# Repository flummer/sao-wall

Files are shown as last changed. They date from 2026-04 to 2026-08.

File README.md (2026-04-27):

# SAO Wall

This is a design for a large PCB (300x400mm) with 16 SAO connectors to work either as a standalone display (fits in an IKEA RÖDALM picture frame) or be monted along with other panels to form a larger wall for displaying many SAOs.

This is heavily inspired by [Brian Benchoffs SAO Wall](https://bbenchoff.github.io/pages/ShittyWall.html), that has been used at several Supercon events, but this design does a few things slightly different, not least the power setup.

## Main concept and idea

The design is separated into two parts:

- SAO Connector board, which is the large PCB, that has all the connectors, polyfuses for each output and then a set of connectors for hooking up to the 4 power rails, the 2 I2C busses and all the GPIO pins for all SAOs
- USB-C PD and Pico controll board is the smaller board that has the voltage regulators (4x AP63203WU-7 buck converters), USB-C PD controller (STUSB4531) and a footprint for a Raspberry Pi Pico (1 or 2).

The setup with two boards is done so that the more generic part (the connector PCB) that is also a bit on the expensive side can be ordered once and maybe a combined order for multiple people, and then the more opinionated element with the powering circuit and maybe a micro controller can be easier made in low volume (most simple is a piece of proto board and a simple 3.3v poser supply).

The USB-C PD power setup that is included here is meant to work nicely with most USB-C power supplies and at the same time be able to power all 16 SAOs to the full specification of the SAO standard (250mA @ 3.3V for each SAO).

The Raspberry Pi Pico is connected very similar to hos the [Hackaday SAO Badge](https://github.com/Hack-a-Day/2024-Supercon-8-Add-On-Badge) was made, with 2 I2C busses (using the same pins) and hooked up to GPIO pins of most of the SAOs (10 out of the 16) as there is a limited number of available connections on the Pico. It's not 100% pin compatible with the Hackaday SAO Badge, but it should be an easy tweak if you would like to run the same firmware.

## Designed in KiCad v10

To open the project, you will need to install the most recent release (v10), KiCad v9 or earlier won't open this design directly.

[Electronics schematics for the connector board as a PDF file](https://github.com/flummer/sao-wall/blob/main/sao-connector-board-schematics.pdf) and [Electronics schematics for the USB-C PD and Pico control board as a PDF file](https://github.com/flummer/sao-wall/blob/main/usb-pd-pico-controller-schematics.pdf) are included for reference.

## License

The hardware design of the `main` branch of this repository is released under the following license:

* the "Creative Commons Attribution-ShareAlike 4.0 International License"
  (CC BY-SA 4.0) full text of this license is included in the LICENSE file
  and a copy can also be found at
  [http://creativecommons.org/licenses/by-sa/4.0/](http://creativecommons.org/licenses/by-sa/4.0/)

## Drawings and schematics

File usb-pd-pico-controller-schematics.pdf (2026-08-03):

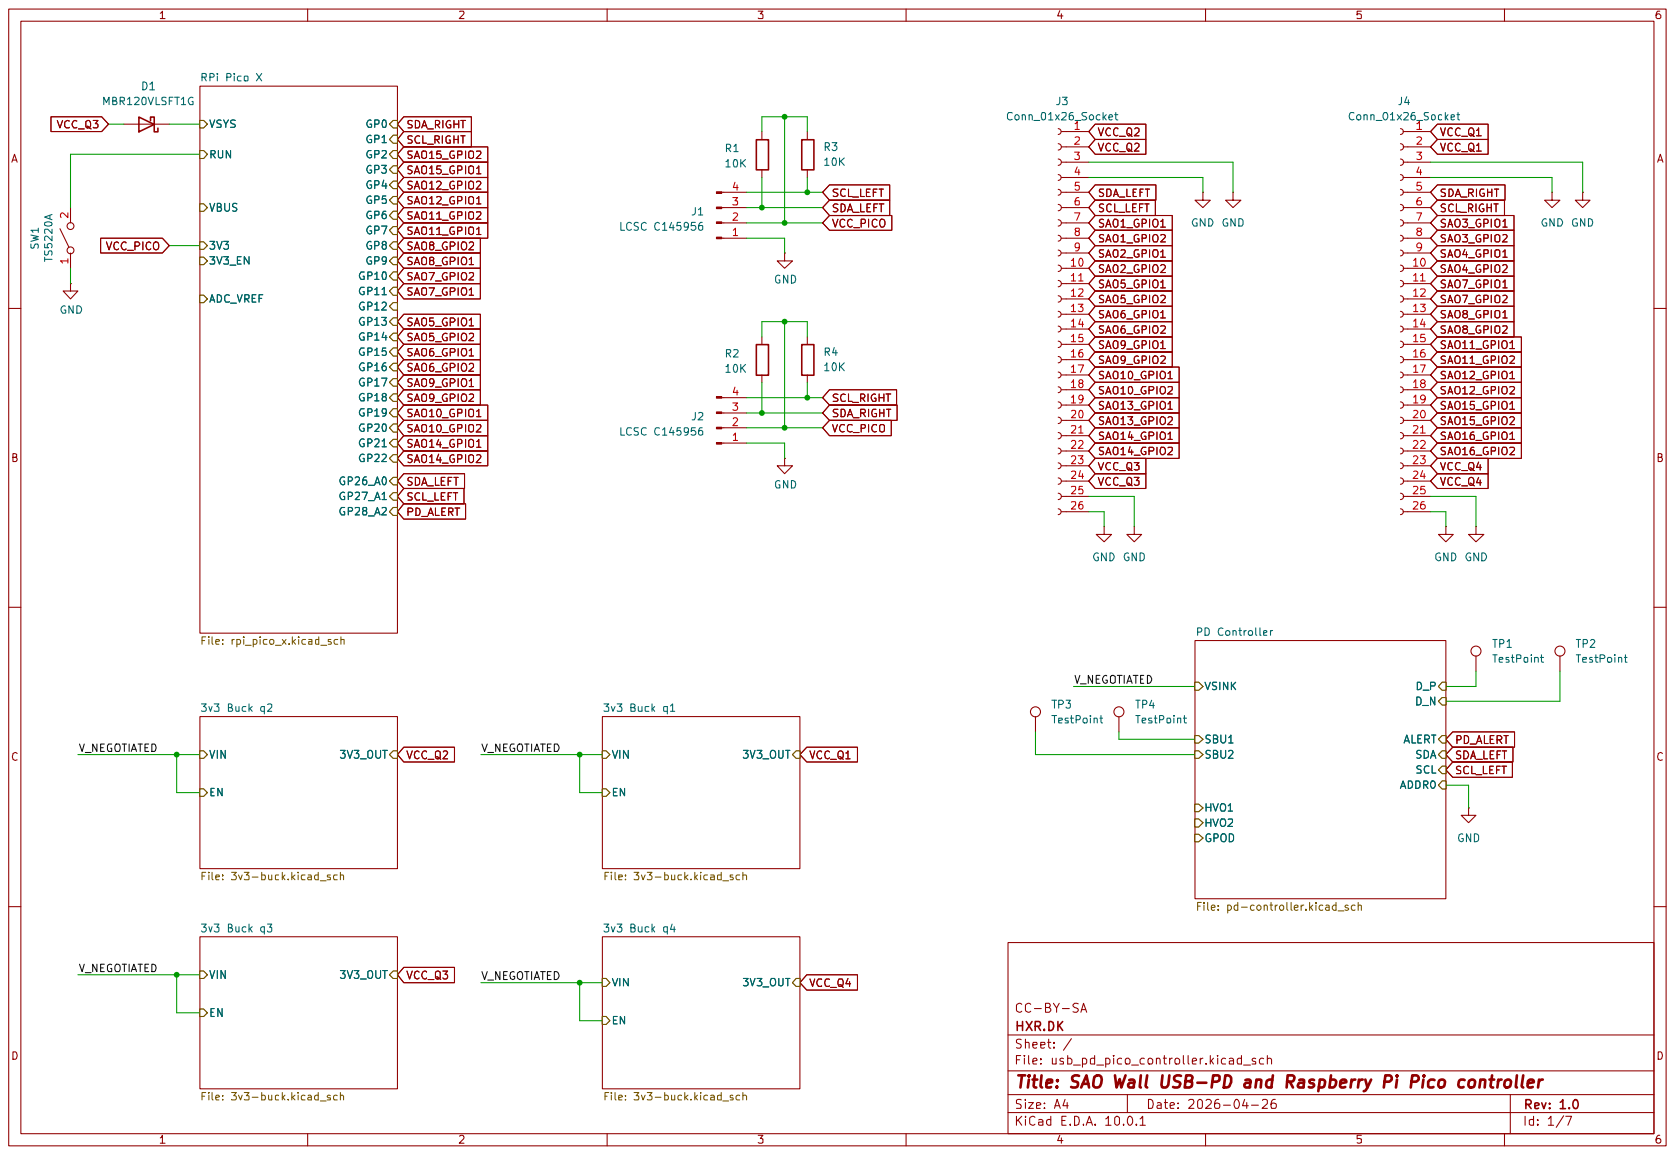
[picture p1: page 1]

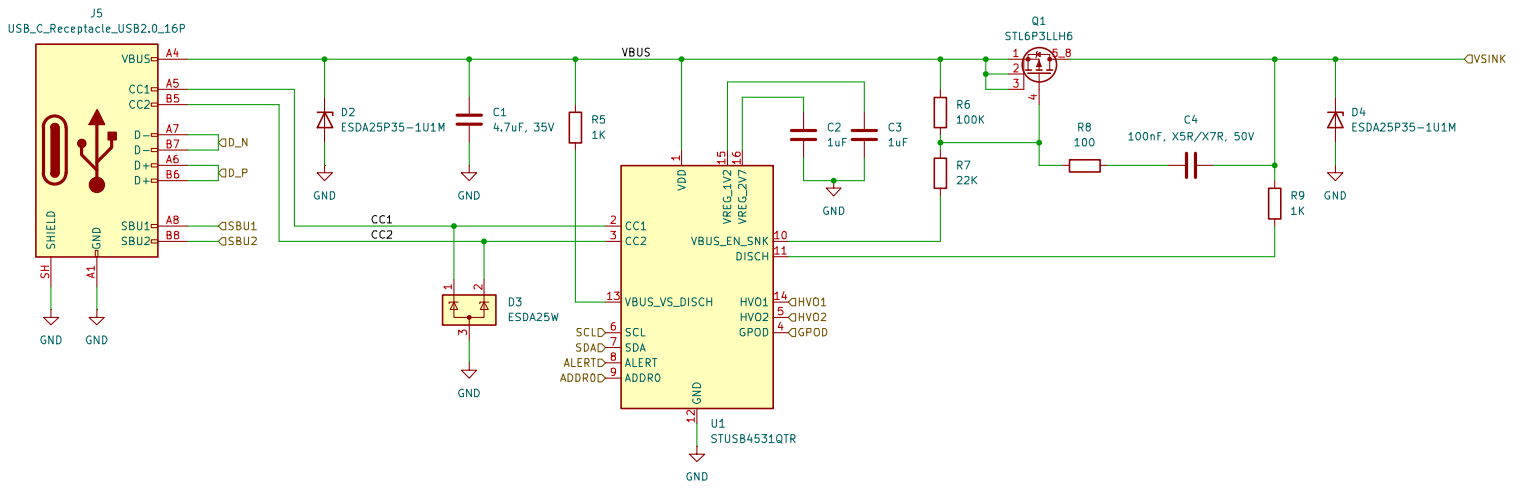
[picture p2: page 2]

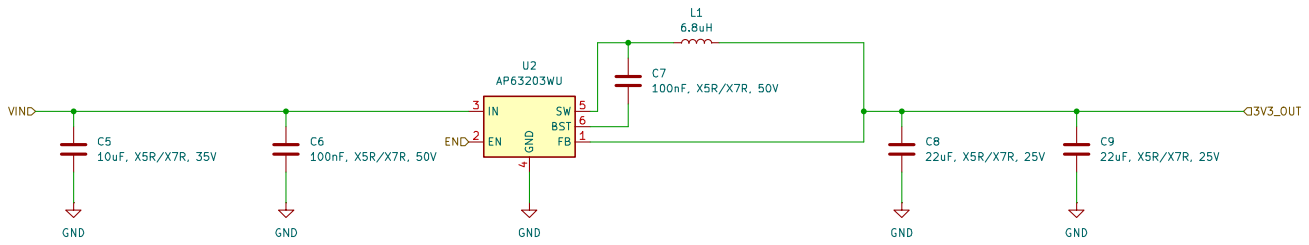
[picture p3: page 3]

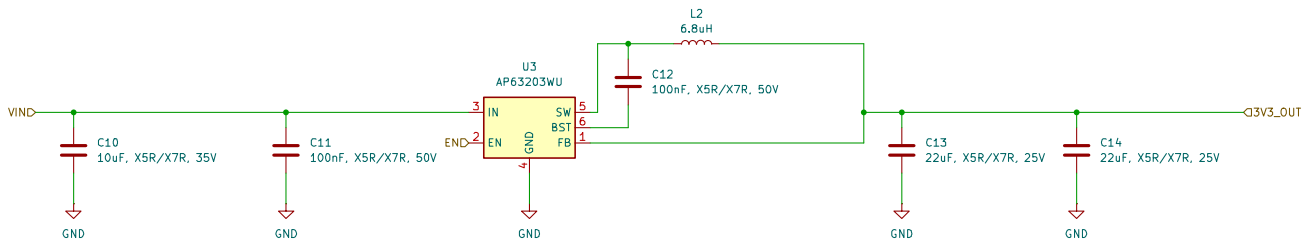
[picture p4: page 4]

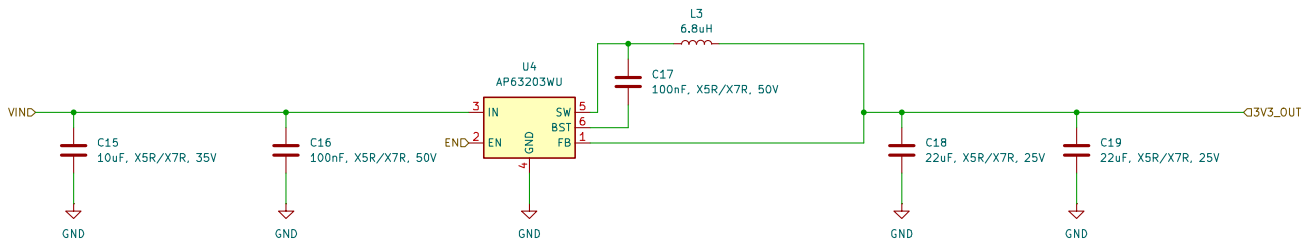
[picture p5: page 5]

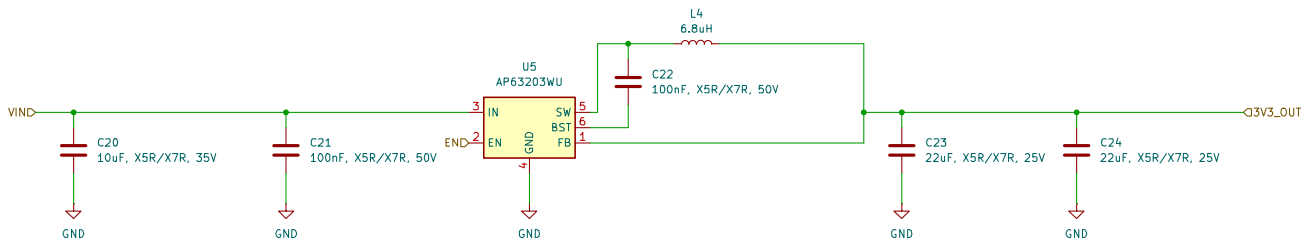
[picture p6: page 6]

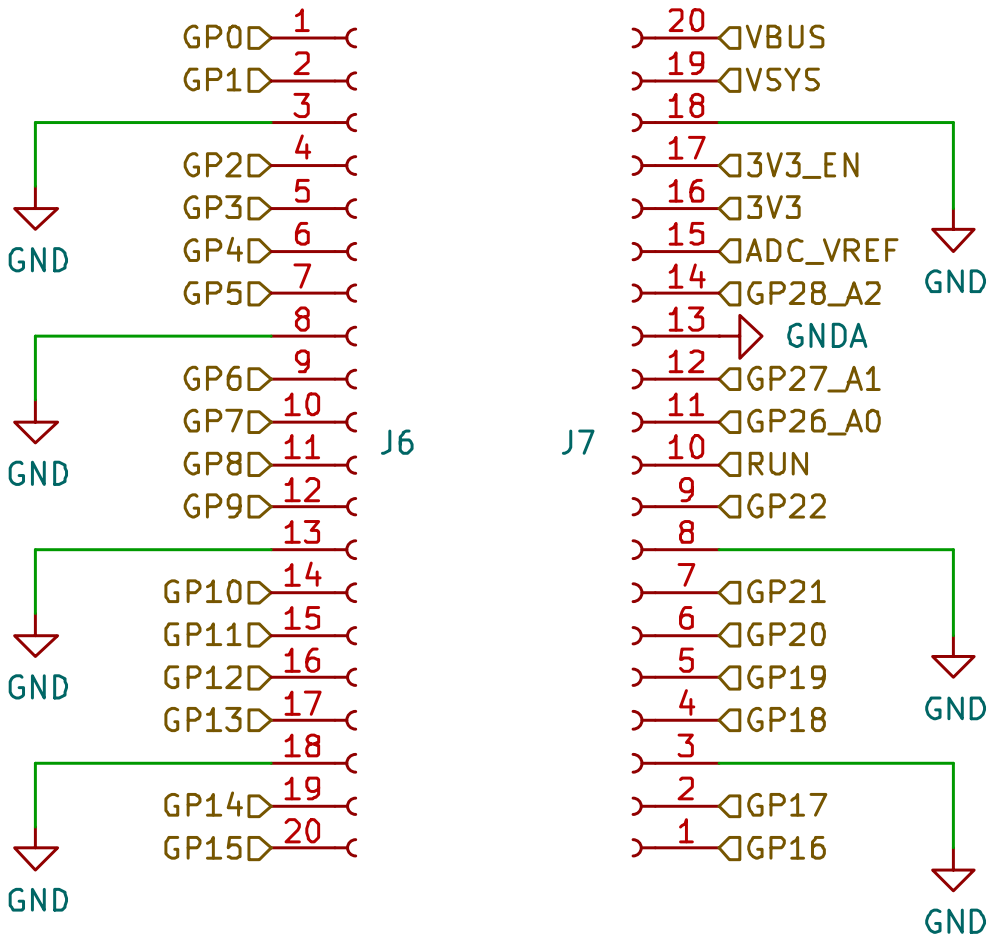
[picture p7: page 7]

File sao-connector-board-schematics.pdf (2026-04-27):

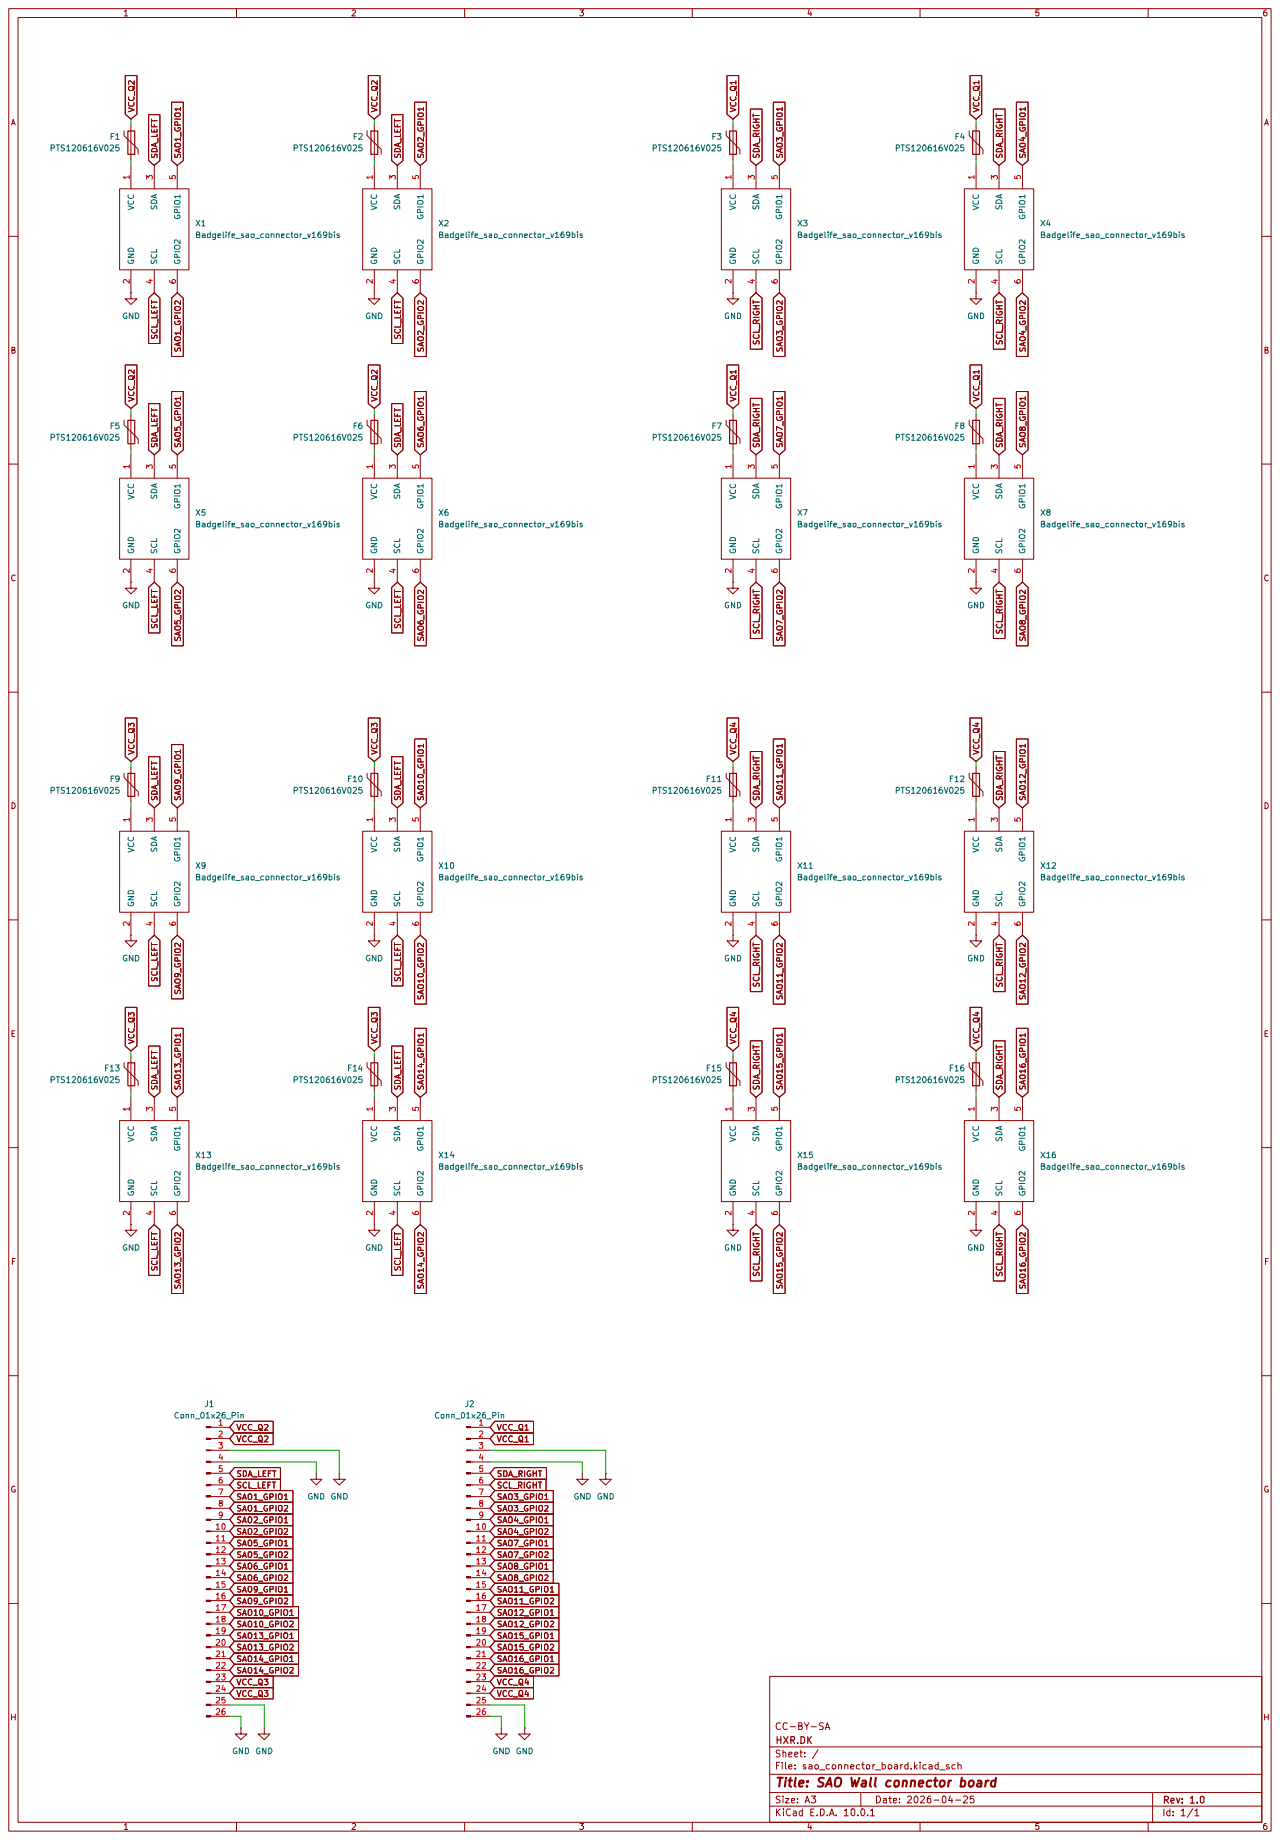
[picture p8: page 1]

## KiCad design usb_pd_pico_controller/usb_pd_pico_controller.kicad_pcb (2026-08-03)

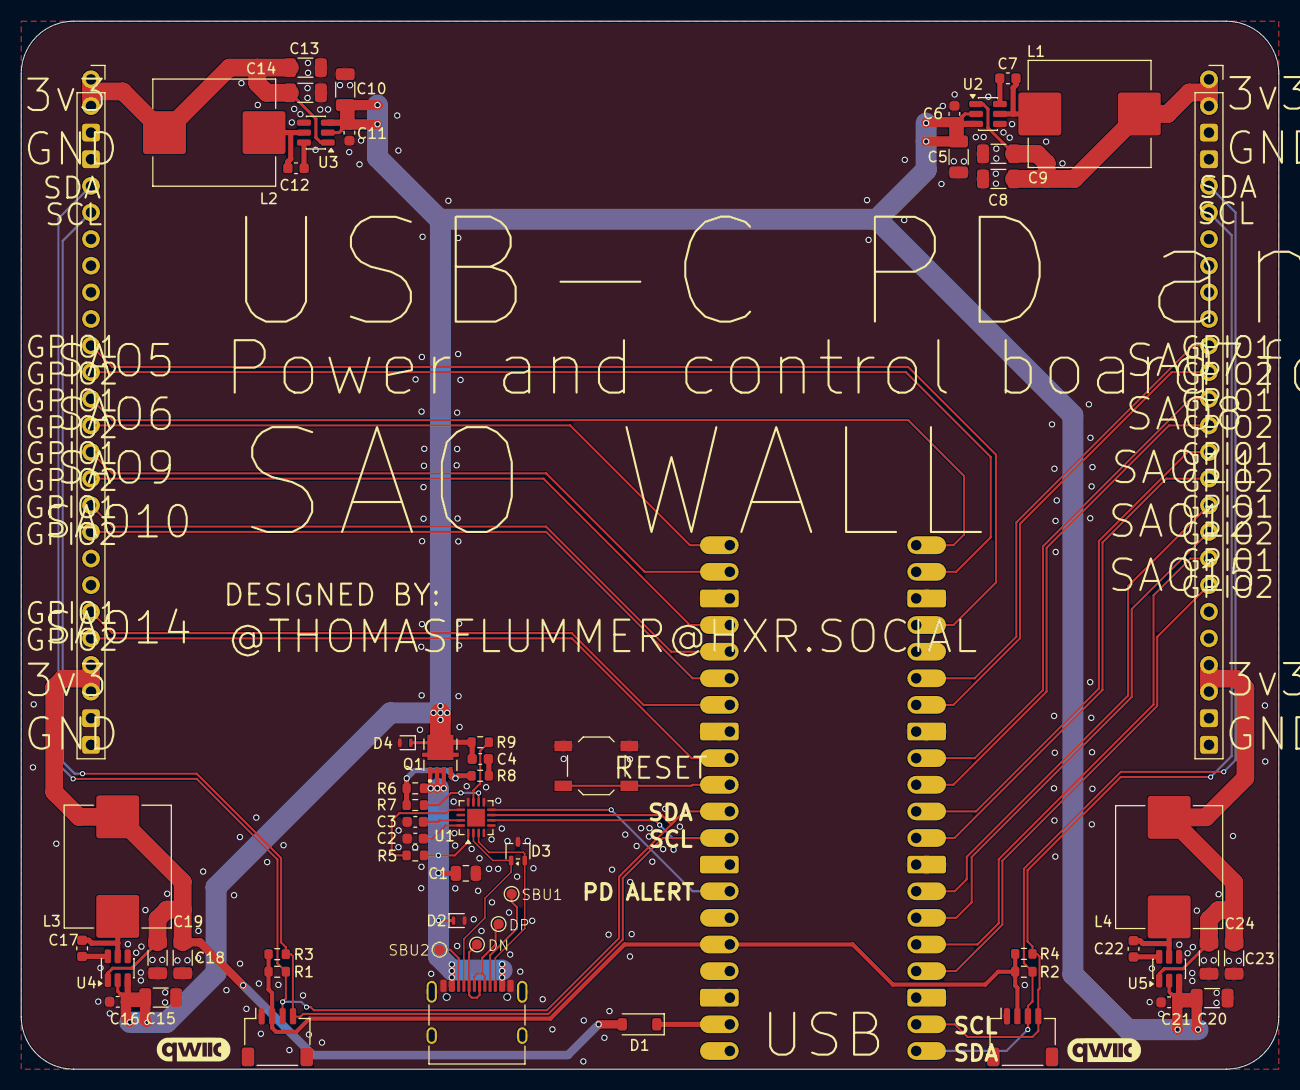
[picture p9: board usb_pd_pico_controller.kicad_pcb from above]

Board: 2 copper layers, 120.0 x 100.0 mm, 59 parts (0 on the bottom side), 56 nets.

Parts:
C1: 4.7uF, 35V; C_0805_2012Metric
C2, C3: 1uF; C_0603_1608Metric
C4, C6, C7, C11, C12, C16, C17, C21, C22: 100nF, X5R/X7R, 50V; C_0603_1608Metric
C5, C10, C15, C20: 10uF, X5R/X7R, 35V; C_1206_3216Metric
C8, C9, C13, C14, C18, C19, C23, C24: 22uF, X5R/X7R, 25V; C_1206_3216Metric
D1: MBR120VLSFT1G; D_SOD-123
D2, D4: ESDA25P35-1U1M; ST_QFN-2L_1.6x1.0mm
D3: ESDA25W; SOT-323_SC-70
J1, J2: LCSC C145956; JST_SH_SM04B-SRSS-TB_1x04-1MP_P1.00mm_Horizontal
J3, J4: Conn_01x26_Socket; PinSocket_1x26_P2.54mm_Vertical
J5: USB_C_Receptacle_USB2.0_16P; USB_C_Receptacle_XKB_U262-16XN-4BVC11
J6, J7: Conn_01x20_Socket; PinSocket_1x20_P2.54mm_Vertical
L1, L2, L3, L4: 6.8uH; L_Sunlord_MWSA1005S
Q1: STL6P3LLH6; TRANS_STL6P3LLH6
R1, R2, R3, R4: 10K; R_0603_1608Metric
R5, R9: 1K; R_0603_1608Metric
R6: 100K; R_0603_1608Metric
R7: 22K; R_0603_1608Metric
R8: 100; R_0603_1608Metric
SW1: TS5220A; SW_SPST_TL3342
TP1, TP2, TP3, TP4: TestPoint; TestPoint_Pad_D1.0mm
U1: STUSB4531QTR; QFN-16-1EP_3x3mm_P0.5mm_EP1.7x1.7mm
U2, U3, U4, U5: AP63203WU; TSOT-23-6

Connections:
/PD Controller/CC1: D3.1 (K), J5.A5 (CC1), U1.2 (CC1)
/PD Controller/CC2: D3.2 (K), J5.B5 (CC2), U1.3 (CC2)
/PD Controller/D_N: J5.A7 (D-), J5.B7 (D-), TP2.1 (1_1)
/PD Controller/D_P: J5.A6 (D+), J5.B6 (D+), TP1.1 (1_1)
/PD Controller/SBU1: J5.A8 (SBU1), TP4.1 (1_1)
/PD Controller/SBU2: J5.B8 (SBU2), TP3.1 (1_1)
/PD Controller/VBUS: C1.1, D2.1 (K), J5.A4 (VBUS), J5.A9 (VBUS), J5.B4 (VBUS), J5.B9 (VBUS), Q1.1 (S1), Q1.2 (S1), Q1.3 (S1), R5.1, R6.1, U1.1 (VDD)
/RPi Pico X/RUN: J7.10, SW1.2 (B)
/RPi Pico X/VSYS: D1.1 (K), J7.19
/V_NEGOTIATED: C4.2, C5.1, C6.1, C10.1, C11.1, C15.1, C16.1, C20.1, C21.1, D4.1 (K), Q1.5_8 (D1), R9.1, U2.2 (EN), U2.3 (IN), U3.2 (EN), U3.3 (IN), U4.2 (EN), U4.3 (IN), U5.2 (EN), U5.3 (IN)
GND: C1.2, C2.2, C3.2, C5.2, C6.2, C8.2, C9.2, C10.2, C11.2, C13.2, C14.2, C15.2, C16.2, C18.2, C19.2, C20.2, C21.2, C23.2, C24.2, D2.2 (A), D3.3 (A), D4.2 (A), J1.1, J2.1, J3.3, J3.4, J3.25, J3.26, J4.3, J4.4, J4.25, J4.26, J5.A1 (GND), J5.A12 (GND), J5.B1 (GND), J5.B12 (GND), J5.SH (SHIELD), J6.3, J6.8, J6.13, J6.18, J7.3, J7.8, J7.18, SW1.1 (A), U1.9 (ADDR0), U1.12 (GND), U2.4 (GND), U3.4 (GND), U4.4 (GND), U5.4 (GND)
unnamed: C4.1, R8.1
unnamed: Q1.4 (G1), R6.2, R7.1, R8.2
unnamed: R9.2, U1.11 (DISCH)
unnamed: R7.2, U1.10 (VBUS_EN_SNK)
unnamed: R5.2, U1.13 (VBUS_VS_DISCH)
unnamed: C3.1, U1.15 (VREG_1V2)
unnamed: C2.1, U1.16 (VREG_2V7)
unnamed: C7.2, U2.6 (BST)
unnamed: C7.1, L1.1, U2.5 (SW)
unnamed: C12.2, U3.6 (BST)
unnamed: C12.1, L2.1, U3.5 (SW)
unnamed: C17.2, U4.6 (BST)
unnamed: C17.1, L3.1, U4.5 (SW)
unnamed: C22.2, U5.6 (BST)
unnamed: C22.1, L4.1, U5.5 (SW)
PD_ALERT: J7.14, U1.8 (ALERT)
SAO5_GPIO1: J3.11, J6.17
SAO5_GPIO2: J3.12, J6.19
SAO6_GPIO1: J3.13, J6.20
SAO6_GPIO2: J3.14, J7.1
SAO7_GPIO1: J4.11, J6.15
SAO7_GPIO2: J4.12, J6.14
SAO8_GPIO1: J4.13, J6.12
SAO8_GPIO2: J4.14, J6.11
SAO9_GPIO1: J3.15, J7.2
SAO9_GPIO2: J3.16, J7.4
SAO10_GPIO1: J3.17, J7.5
SAO10_GPIO2: J3.18, J7.6
SAO11_GPIO1: J4.15, J6.10
SAO11_GPIO2: J4.16, J6.9
SAO12_GPIO1: J4.17, J6.7
SAO12_GPIO2: J4.18, J6.6
SAO14_GPIO1: J3.21, J7.7
SAO14_GPIO2: J3.22, J7.9
SAO15_GPIO1: J4.19, J6.5
SAO15_GPIO2: J4.20, J6.4
SCL_LEFT: J1.4, J3.6, J7.12, R3.2, U1.6 (SCL)
SCL_RIGHT: J2.4, J4.6, J6.2, R4.2
SDA_LEFT: J1.3, J3.5, J7.11, R1.2, U1.7 (SDA)
SDA_RIGHT: J2.3, J4.5, J6.1, R2.2
VCC_PICO: J1.2, J2.2, J7.16, R1.1, R2.1, R3.1, R4.1
VCC_Q1: C8.1, C9.1, J4.1, J4.2, L1.2, U2.1 (FB)
VCC_Q2: C13.1, C14.1, J3.1, J3.2, L2.2, U3.1 (FB)
VCC_Q3: C18.1, C19.1, D1.2 (A), J3.23, J3.24, L3.2, U4.1 (FB)
VCC_Q4: C23.1, C24.1, J4.23, J4.24, L4.2, U5.1 (FB)

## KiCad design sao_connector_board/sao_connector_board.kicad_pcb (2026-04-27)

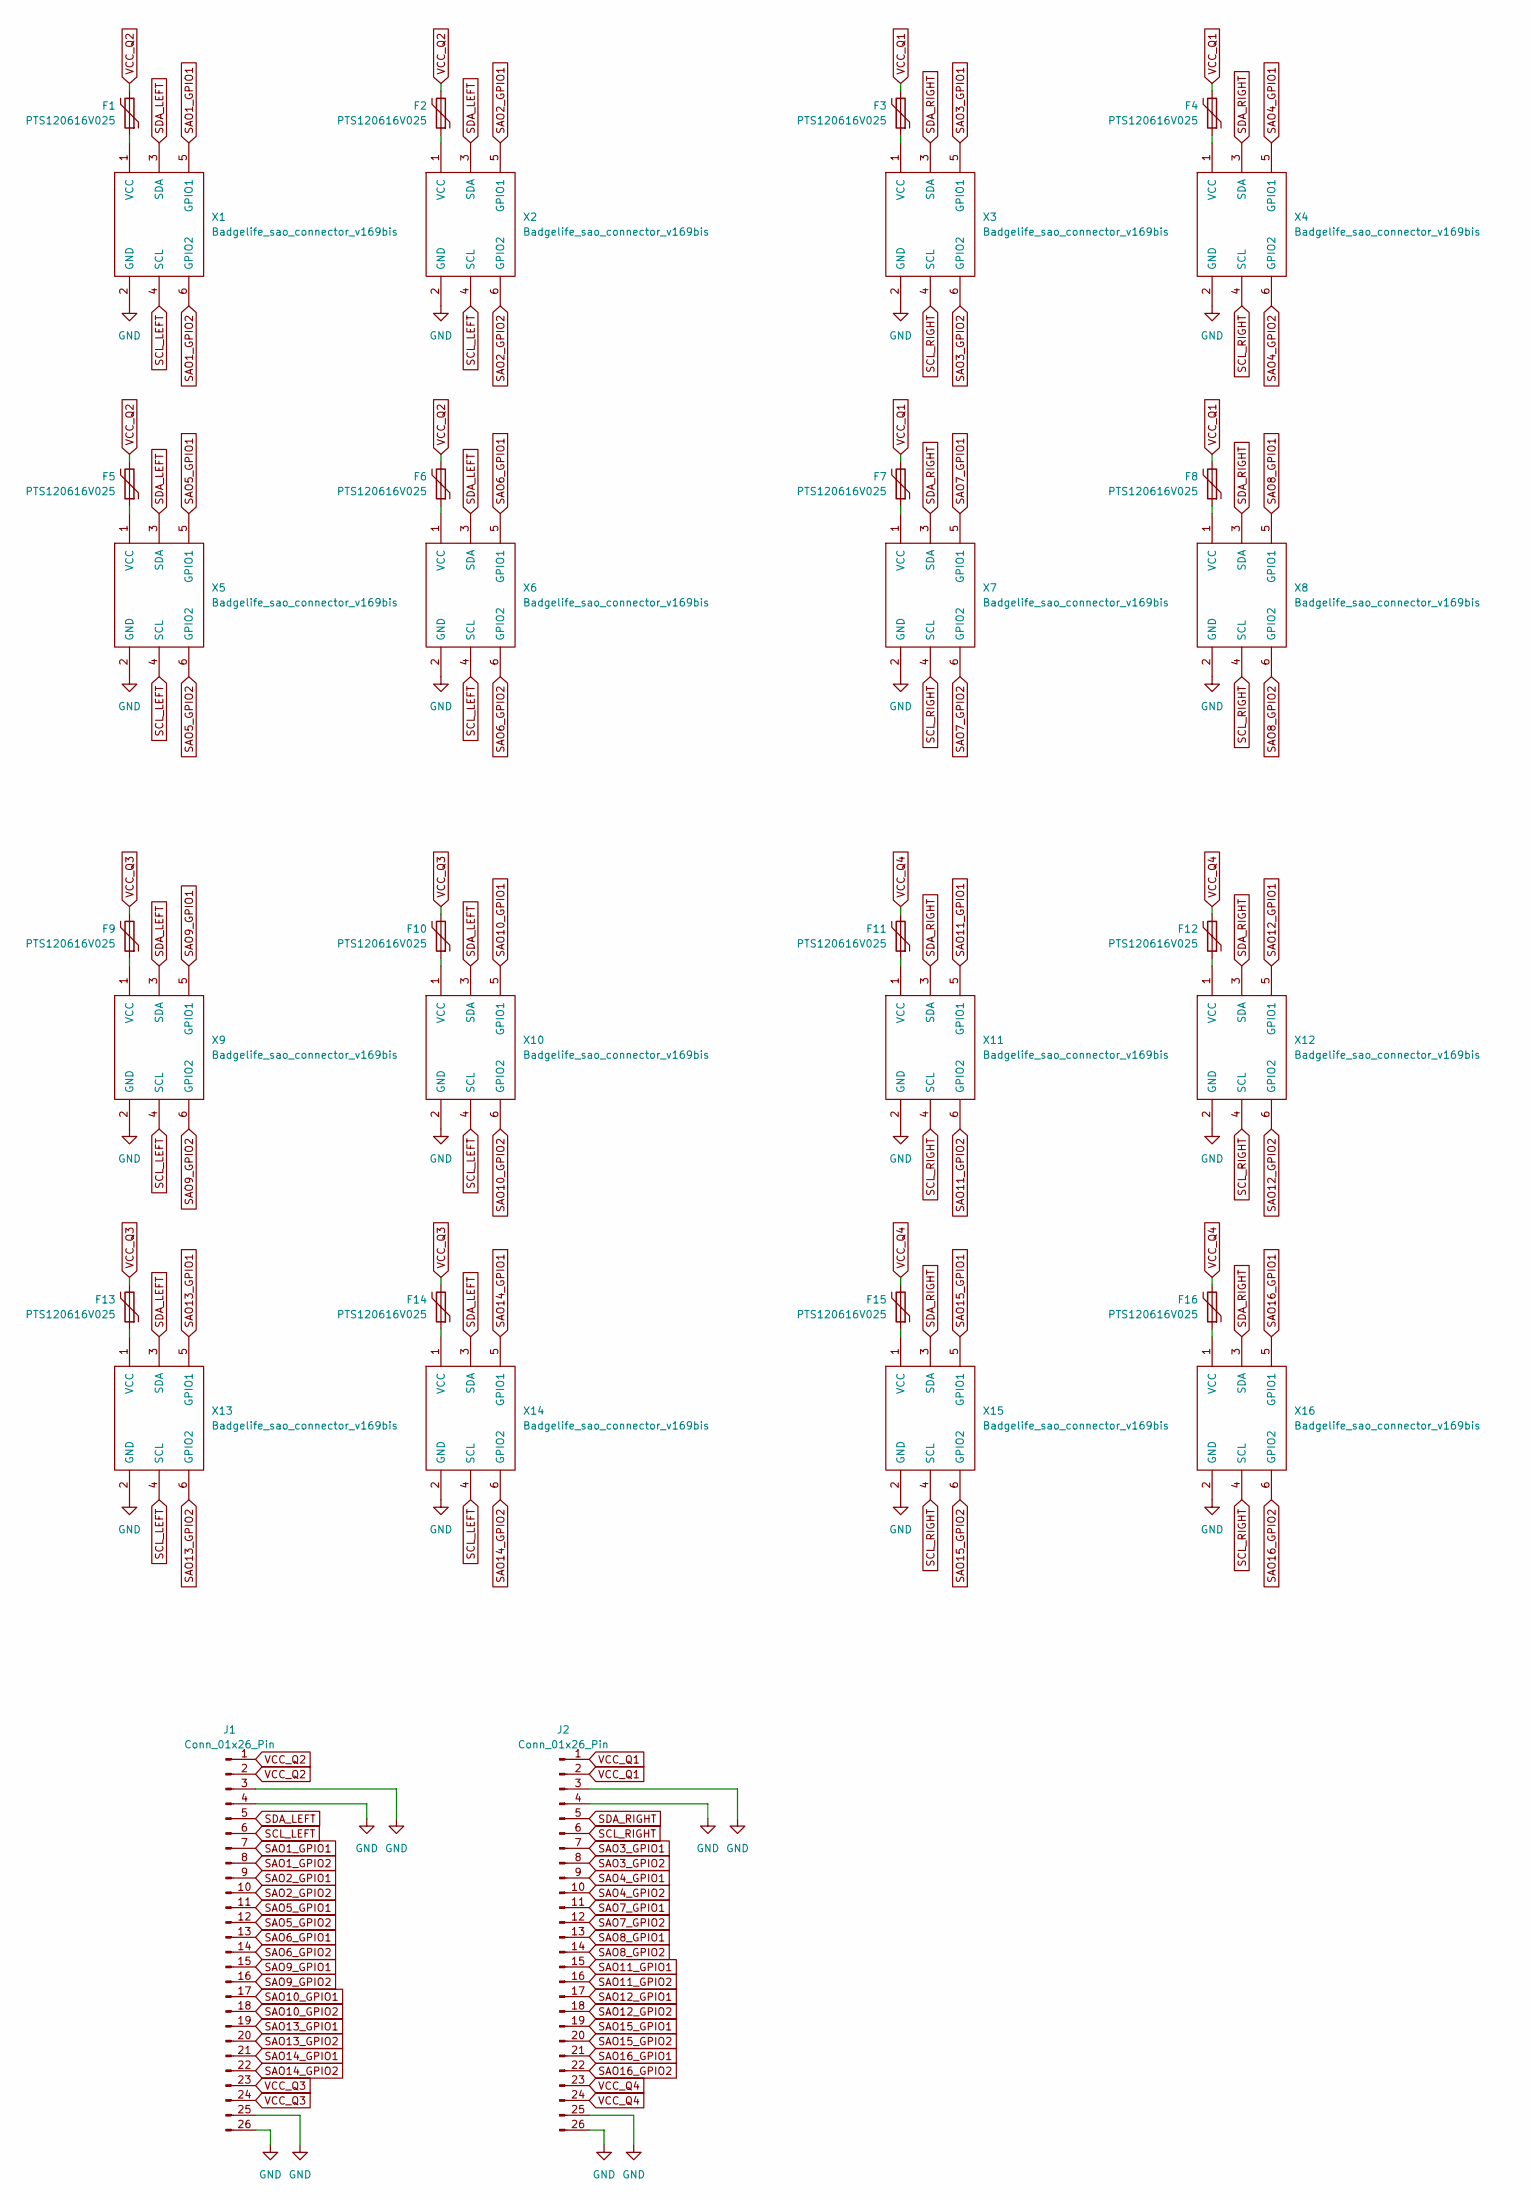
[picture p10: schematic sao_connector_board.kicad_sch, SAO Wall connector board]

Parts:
F1, F2, F3, F4, F5, F6, F7, F8, F9, F10, F11, F12, F13, F14, F15, F16: PTS120616V025; Fuse_1206_3216Metric_Pad1.42x1.75mm_HandSolder
J1, J2: Conn_01x26_Pin; PinHeader_1x26_P2.54mm_Vertical_SMD_Pin1Left
X1, X2, X3, X4, X5, X6, X7, X8, X9, X10, X11, X12, X13, X14, X15, X16: Badgelife_sao_connector_v169bis; Badgelife-SAOv169-BADGE-2x3-clean-front

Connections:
GND: J1.3, J1.4, J1.25, J1.26, J2.3, J2.4, J2.25, J2.26, X1.2 (GND), X2.2 (GND), X3.2 (GND), X4.2 (GND), X5.2 (GND), X6.2 (GND), X7.2 (GND), X8.2 (GND), X9.2 (GND), X10.2 (GND), X11.2 (GND), X12.2 (GND), X13.2 (GND), X14.2 (GND), X15.2 (GND), X16.2 (GND)
unnamed: F1.1, X1.1 (VCC)
unnamed: F2.1, X2.1 (VCC)
unnamed: F3.1, X3.1 (VCC)
unnamed: F4.1, X4.1 (VCC)
unnamed: F5.1, X5.1 (VCC)
unnamed: F6.1, X6.1 (VCC)
unnamed: F7.1, X7.1 (VCC)
unnamed: F8.1, X8.1 (VCC)
unnamed: F9.1, X9.1 (VCC)
unnamed: F10.1, X10.1 (VCC)
unnamed: F11.1, X11.1 (VCC)
unnamed: F12.1, X12.1 (VCC)
unnamed: F13.1, X13.1 (VCC)
unnamed: F14.1, X14.1 (VCC)
unnamed: F15.1, X15.1 (VCC)
unnamed: F16.1, X16.1 (VCC)
SAO1_GPIO1: J1.7, X1.5 (GPIO1)
SAO1_GPIO2: J1.8, X1.6 (GPIO2)
SAO2_GPIO1: J1.9, X2.5 (GPIO1)
SAO2_GPIO2: J1.10, X2.6 (GPIO2)
SAO3_GPIO1: J2.7, X3.5 (GPIO1)
SAO3_GPIO2: J2.8, X3.6 (GPIO2)
SAO4_GPIO1: J2.9, X4.5 (GPIO1)
SAO4_GPIO2: J2.10, X4.6 (GPIO2)
SAO5_GPIO1: J1.11, X5.5 (GPIO1)
SAO5_GPIO2: J1.12, X5.6 (GPIO2)
SAO6_GPIO1: J1.13, X6.5 (GPIO1)
SAO6_GPIO2: J1.14, X6.6 (GPIO2)
SAO7_GPIO1: J2.11, X7.5 (GPIO1)
SAO7_GPIO2: J2.12, X7.6 (GPIO2)
SAO8_GPIO1: J2.13, X8.5 (GPIO1)
SAO8_GPIO2: J2.14, X8.6 (GPIO2)
SAO9_GPIO1: J1.15, X9.5 (GPIO1)
SAO9_GPIO2: J1.16, X9.6 (GPIO2)
SAO10_GPIO1: J1.17, X10.5 (GPIO1)
SAO10_GPIO2: J1.18, X10.6 (GPIO2)
SAO11_GPIO1: J2.15, X11.5 (GPIO1)
SAO11_GPIO2: J2.16, X11.6 (GPIO2)
SAO12_GPIO1: J2.17, X12.5 (GPIO1)
SAO12_GPIO2: J2.18, X12.6 (GPIO2)
SAO13_GPIO1: J1.19, X13.5 (GPIO1)
SAO13_GPIO2: J1.20, X13.6 (GPIO2)
SAO14_GPIO1: J1.21, X14.5 (GPIO1)
SAO14_GPIO2: J1.22, X14.6 (GPIO2)
SAO15_GPIO1: J2.19, X15.5 (GPIO1)
SAO15_GPIO2: J2.20, X15.6 (GPIO2)
SAO16_GPIO1: J2.21, X16.5 (GPIO1)
SAO16_GPIO2: J2.22, X16.6 (GPIO2)
SCL_LEFT: J1.6, X1.4 (SCL), X2.4 (SCL), X5.4 (SCL), X6.4 (SCL), X9.4 (SCL), X10.4 (SCL), X13.4 (SCL), X14.4 (SCL)
SCL_RIGHT: J2.6, X3.4 (SCL), X4.4 (SCL), X7.4 (SCL), X8.4 (SCL), X11.4 (SCL), X12.4 (SCL), X15.4 (SCL), X16.4 (SCL)
SDA_LEFT: J1.5, X1.3 (SDA), X2.3 (SDA), X5.3 (SDA), X6.3 (SDA), X9.3 (SDA), X10.3 (SDA), X13.3 (SDA), X14.3 (SDA)
SDA_RIGHT: J2.5, X3.3 (SDA), X4.3 (SDA), X7.3 (SDA), X8.3 (SDA), X11.3 (SDA), X12.3 (SDA), X15.3 (SDA), X16.3 (SDA)
VCC_Q1: F3.2, F4.2, F7.2, F8.2, J2.1, J2.2
VCC_Q2: F1.2, F2.2, F5.2, F6.2, J1.1, J1.2
VCC_Q3: F9.2, F10.2, F13.2, F14.2, J1.23, J1.24
VCC_Q4: F11.2, F12.2, F15.2, F16.2, J2.23, J2.24

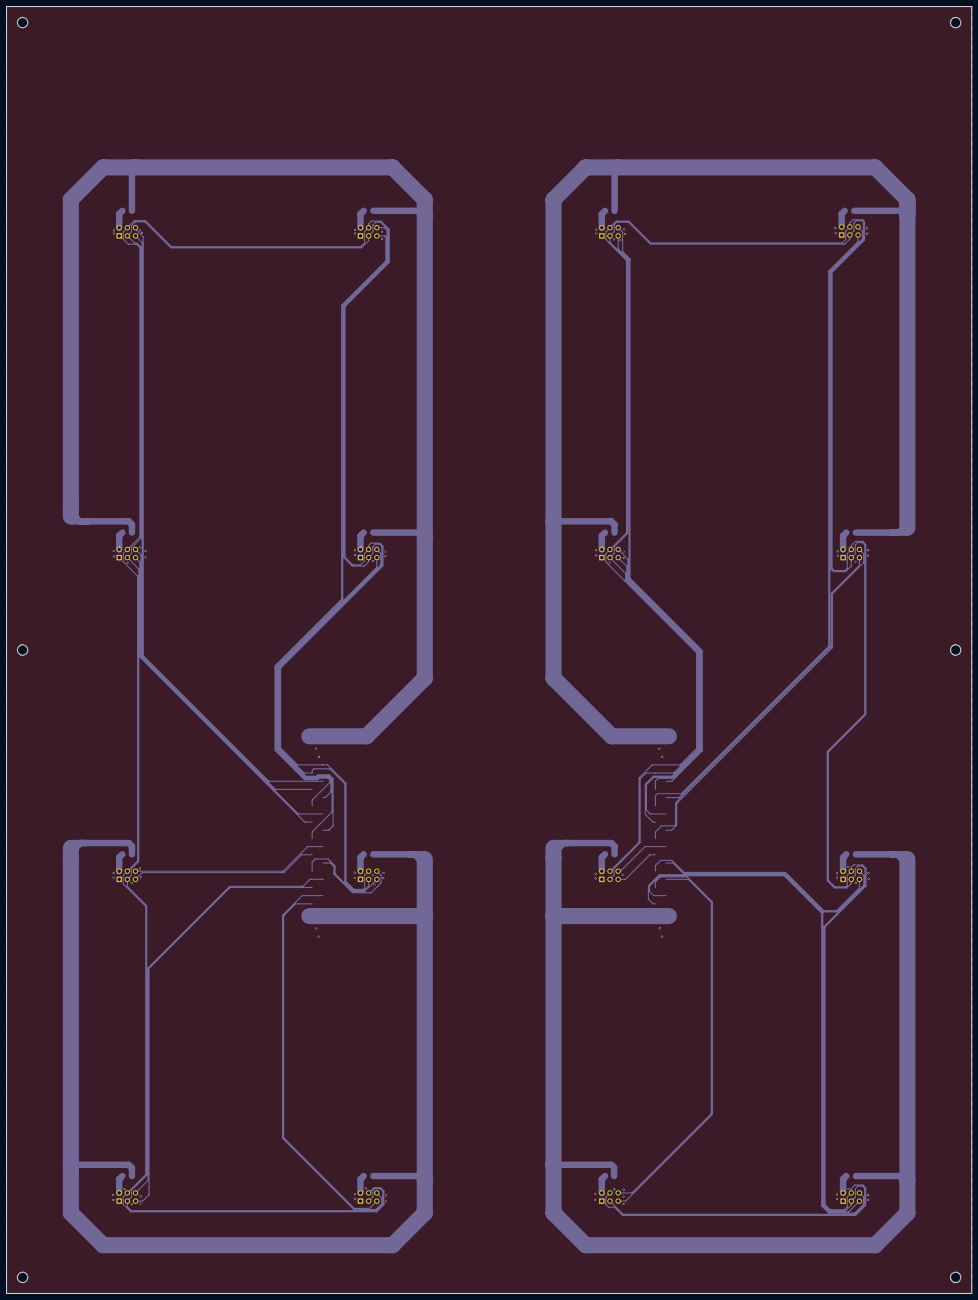
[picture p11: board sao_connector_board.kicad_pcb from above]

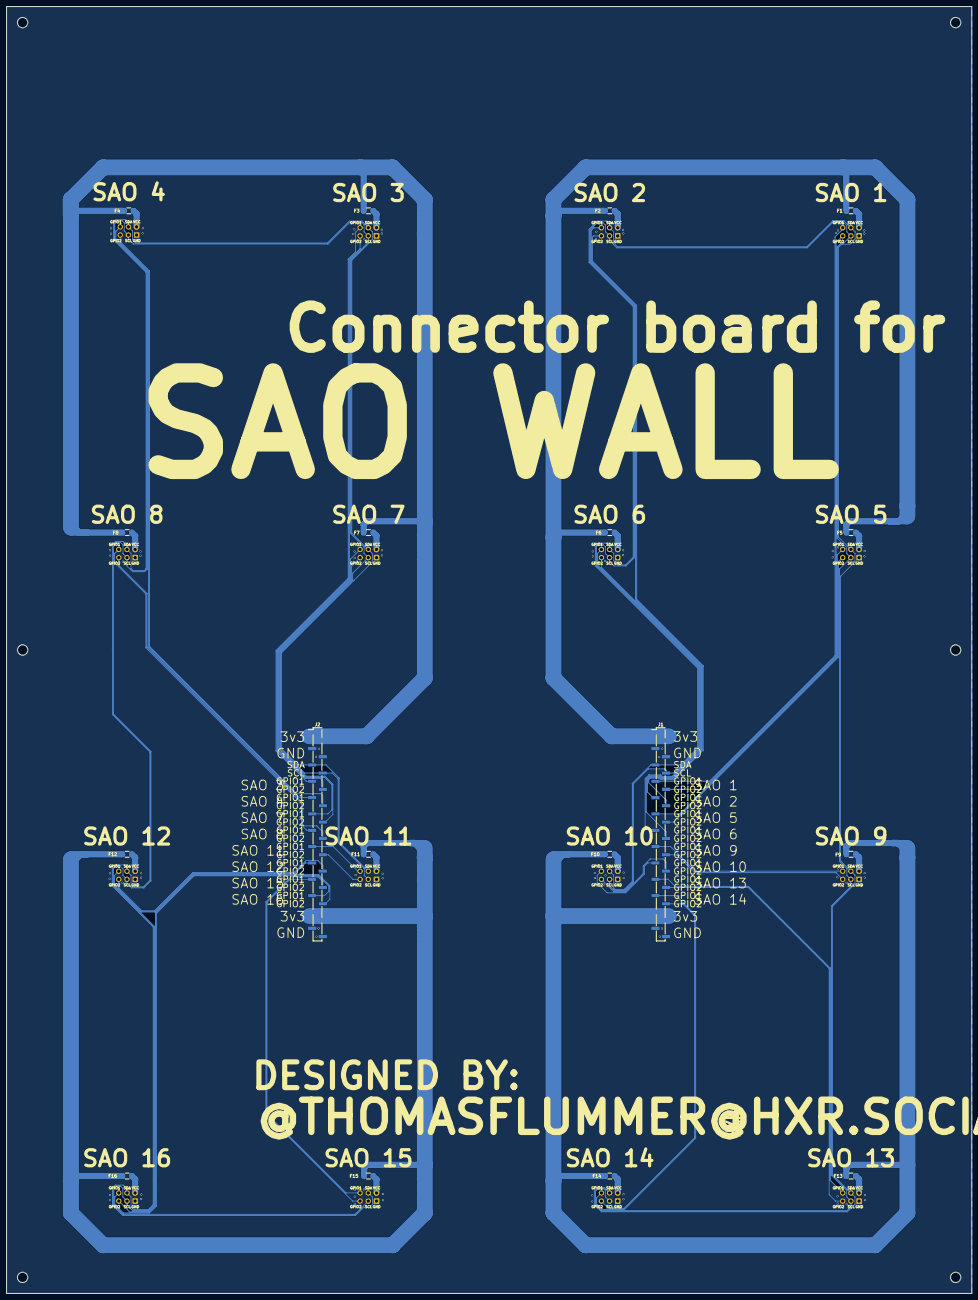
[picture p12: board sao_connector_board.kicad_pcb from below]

Board: 2 copper layers, 300.0 x 400.0 mm, 34 parts (18 on the bottom side), 57 nets.

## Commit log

2026-08-02 Added ibom for PD controller board
2026-08-03 Consolidated BOM item (100nF)
    [pd-controller.kicad_sch, usb_pd_pico_controller.kicad_pcb]
